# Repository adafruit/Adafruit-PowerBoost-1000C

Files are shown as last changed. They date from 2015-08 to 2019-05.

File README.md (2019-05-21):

## Adafruit PowerBoost 1000C
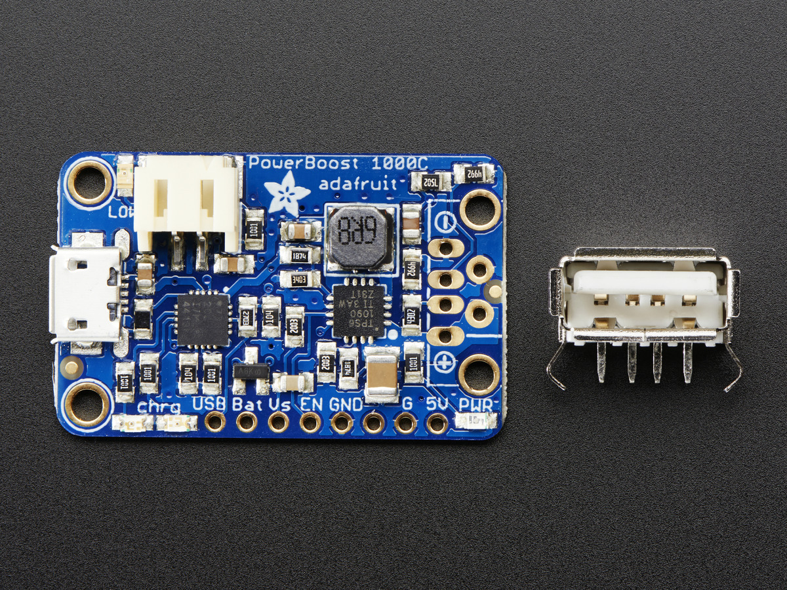
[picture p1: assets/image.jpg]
<a href="http://www.adafruit.com/products/2465"><br/>
Click here to purchase one from the Adafruit shop</a>

PowerBoost 1000C is the perfect power supply for your portable project! With a built-in load-sharing battery charger circuit, you'll be able to keep your power-hungry project running even while recharging the battery! This little DC/DC boost converter module can be powered by any 3.7V LiIon/LiPoly battery, and convert the battery output to 5.2V DC for running your 5V projects.

If you dont need the 1A battery charger, smart load-sharing, or 1A iOS resistors, check out the Powerboost 500C

Like our popular 5V 1A USB wall adapter, we tweaked the output to be 5.2V instead of a straight-up 5.0V so that there's a little bit of 'headroom' for long cables, high draw, the addition of a diode on the output if you wish, etc. The 5.2V is safe for all 5V-powered electronics like Arduino, Raspberry Pi, or Beagle Bone while preventing icky brown-outs during high current draw because of USB cable resistance.

The PowerBoost 1000C has at the heart a TPS61090 boost converter from TI. This boost converter chip has some really nice extras such as low battery detection, 2A internal switch, synchronous conversion, excellent efficiency, and 700KHz high-frequency operation. 

PCB files for Adafruit PowerBoost 1000C
-  https://www.adafruit.com/product/2465

### License

Adafruit invests time and resources providing this open source design, please support Adafruit and open-source hardware by purchasing products from [Adafruit](https://www.adafruit.com)!

All text above must be included in any redistribution

Designed by Limor Fried/Ladyada for Adafruit Industries.
Creative Commons Attribution/Share-Alike, all text above must be included in any redistribution. 
See license.txt for additional information.

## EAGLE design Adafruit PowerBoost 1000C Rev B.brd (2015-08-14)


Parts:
B1: JST 2-PH; JSTPH2
C1, C7, C8: 10uF; 0805-NO
C2: 2.2uF; 0805-NO
C4: 0.1uF; 0805_10MGAP
C6: 100uF; C1210
CHRG/LBO: ORANGE; CHIPLED_0805_NOOUTLINE
CN1: USBA_FEMALE; USB_HOST-PTH
CN4: MicroUSB; 4UCONN_20329
DONE: GREEN; CHIPLED_0805_NOOUTLINE
FID1, FID2, FID3: FIDUCIAL""; FIDUCIAL_1MM
JP2: HEADER-1X8ROUND; 1X08_ROUND
L1: 6.8uH; INDUCTOR_5X5MM_TDK_VLC5045
LED1: RED; CHIPLED_0805_NOOUTLINE
LED2: BLUE; CHIPLED_0805_NOOUTLINE
R1: 1.87M; _0805MP
R2: 340K; _0805MP
R3: 1.87M; 0805-NO
R4, R13: 200K; 0805-NO
R5, R8, R14, R20: 1K; 0805-NO
R6: 270K; 0805-NO
R7, R17: 100K; 0805-NO
R9: 43K; 0805-NO
R10: 49.9K; 0805-NO
R11: 75K 1%; 0805-NO
R12: 49.9K 1%; 0805-NO
R16: 1.0K; 0805-NO
T1: MMUN2133LT1G; SC59-BEC
THERM: 15K; 0805-NO
U1: TPS61090RSAR; PVQFN-16
U2: MCP73871; QFN20_4MM
U$10, U$11: MOUNTINGHOLE2.5; MOUNTINGHOLE_2.5_PLATED
X1: TERMBLOCK_1X2; TERMBLOCK_1X2-3.5MM

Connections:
5.0V: C2.1, C6.1, CN1.VBUS, JP2.8, R3.2, R5.1, R9.2, R11.2, U1.1 (VOUT), U1.15 (VOUT), U1.16 (VOUT), X1.2
D+: CN1.D+, R11.1, R12.1
D-: CN1.D-, R9.1, R10.1
ENABLE: JP2.4, R13.2, U1.11 (EN)
GND: B1.1 (-), C1.2, C2.2, C4.2, C6.2, C7.2, C8.2, CN1.GND, CN4.BASE@1 (GND), CN4.BASE@2 (GND), CN4.GND, CN4.SPRT@1 (GND), CN4.SPRT@2 (GND), CN4.SPRT@3 (GND), CN4.SPRT@4 (GND), JP2.5, JP2.7, LED1.C, LED2.C, R2.1, R4.1, R7.2, R10.2, R12.2, R16.1, R17.1, THERM.1, U1.5 (PGND), U1.6 (PGND), U1.7 (PGND), U1.10 (SYNC), U1.13 (GND), U1.P$18 (PGND), U1.P$19 (PGND), U1.P$20 (PGND), U1.P$21 (PGND), U1.P$22 (PGND), U1.THERMAL (PGND), U2.P$10 (VSS1), U2.P$11 (VSS2), U2.P$21 (THERMAL), X1.1
LBO: JP2.6, T1.B, U1.12 (LBO)
unnamed: L1.P$2 (2), U1.3 (SW), U1.4 (SW)
unnamed: LED1.A, R20.1
unnamed: R1.1, R2.2, U1.9 (LBI)
unnamed: LED2.A, R5.2
unnamed: R3.1, R4.2, U1.14 (FB)
unnamed: R20.2, T1.C
unnamed: R6.1, R7.1, U2.P$2 (VPCC)
unnamed: DONE.C, R14.2
unnamed: R14.1, U2.P$7 (STAT2)
unnamed: THERM.2, U2.P$5 (THERM)
unnamed: R8.1, U2.P$8 (STAT1/LBO)
unnamed: CHRG/LBO.C, R8.2
unnamed: R17.2, U2.P$12 (PROG3)
unnamed: R16.2, U2.P$13 (PROG1)
VBAT: C1.1, C4.1, JP2.3, L1.P$1 (1), R1.2, R13.1, T1.E, U1.8 (VBAT), U2.P$1 (VOUT1), U2.P$20 (VOUT2)
VBUS: C8.1, CHRG/LBO.A, CN4.VBUS, DONE.A, JP2.1, R6.2, U2.P$3 (SEL), U2.P$4 (PROG2), U2.P$9 (/TE), U2.P$17 (CE), U2.P$18 (VIN1), U2.P$19 (VIN2)
VLIPO: B1.2 (+), C7.1, JP2.2, U2.P$14 (VBAT1), U2.P$15 (VBAT2), U2.P$16 (VBATSENS)

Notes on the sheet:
Both grounds must be connected on the PCB at only one point close to the GND pin.
On/Off Switch
See Pg 15 1st para
6.8uH power w/2A current
R3 = 1.9Mohm for 5.2V R3 = 1.1Mohm for 3.3V
Charge Rate = 1000V/PROG1
1.0K = 1000mA
2.0K = 500mA
No Thermistor:
10K NTC Thermistor:
RT1 = 0, RT2 = 10K
RT1 = TBD, RT2 = TBD



Board: 2 copper layers, 36.1 x 22.9 mm, 47 parts (2 on the bottom side), 23 nets.

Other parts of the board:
U$12: PCBFEAT-REV-040
U$25: SYMBOL_PLUS
U$26: SYMBOL_MINUS
U$28: ADAFRUIT_5MM
U$45: ADAFRUIT_3.5MM

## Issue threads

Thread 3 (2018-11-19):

Does not indicate full charge

SeanHoang2203, 2018-11-19:
I'm not sure if this is an issue or not but when I charge the Li-Po battery while connecting it to my circuits (without turning on the circuits), the green led indicate full charge never light up. When I plug the battery to an external charger, it showed that the battery is full. Any thoughts?

Thank you.

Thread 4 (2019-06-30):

LED Specifications

JohnBarkerPG, 2019-06-30:
What are the specifications of the LEDS in this diagram?

20mA? 2mA? what is the forward voltage of them?

Thanks.

ladyada, 2019-06-30:
~2.3V 20mA

Closed 2019-06-30.

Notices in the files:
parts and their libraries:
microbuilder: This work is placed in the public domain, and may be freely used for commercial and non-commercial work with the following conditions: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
